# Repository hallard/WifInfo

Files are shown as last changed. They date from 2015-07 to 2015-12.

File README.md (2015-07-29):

WifInfo : Wifi Teleinfo server
==============================

This is a server board for Teleinfo French Meter Measure Library, it can be used as a stand alone device web server that can display/send Teleinfo information.

You can see Teleinformation official french datasheet [there][1]

Since this is really dedicated to French energy measuring system, I will continue in French

Pour le moment le logiciel utilisé doit être considéré comme une version béta (voir alpha), même si le hardware est parfaitement fonctionnel, la partie logicielle est loin d'être terminée.

##Fonctionnalités Terminées
- Mise à jour par Wifi (pas besoin de cable) 
- Affichage dans l'interface Web des données de Teleinfo 
- Affichage dans l'interface Web des données système 
- REST API du type http://wifinfo/papp pour récupérer l'étiquette PAPP (par exemple)

##Fonctionnalités à écrire
A terme les fonctionnalités de cette carte seront les suivantes :
- Créer la page WEB de connexion a un Wifi local 
- Créer la page WEB de configuration du Module 
- Envoi des données de téléinfo vers EMONCMS
- Envoi des données de téléinfo vers les box domotique (JEEDOM, EEDOMUS, ...)
- D'autres idées arriveront surement en cours de route...

Vous trouverez un article dédié à cette carte sur mon [blog][3]

##Schémas  
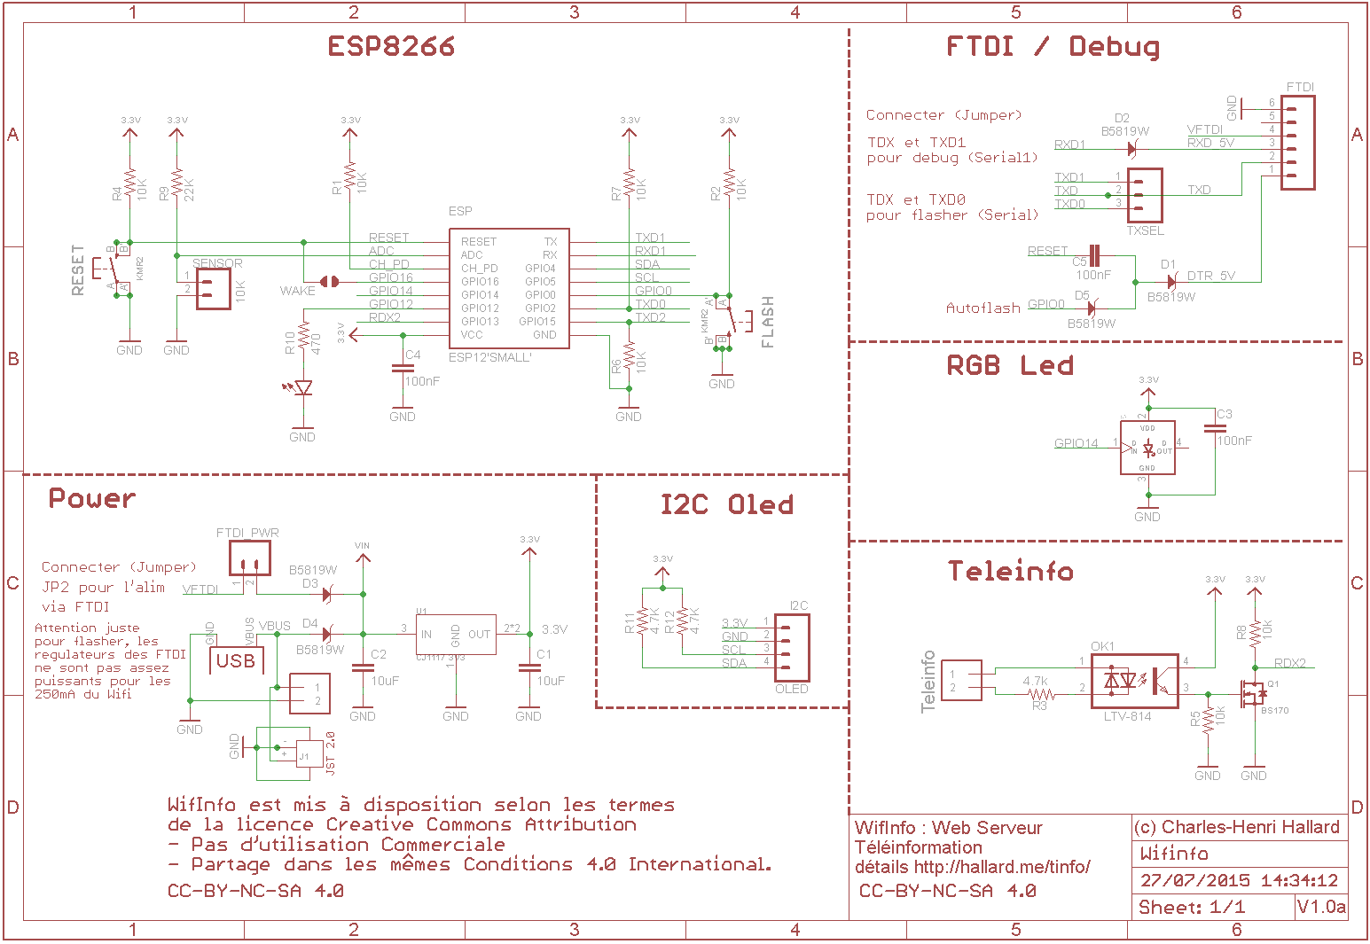
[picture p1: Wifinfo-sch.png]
schematic
  

##Cartes 
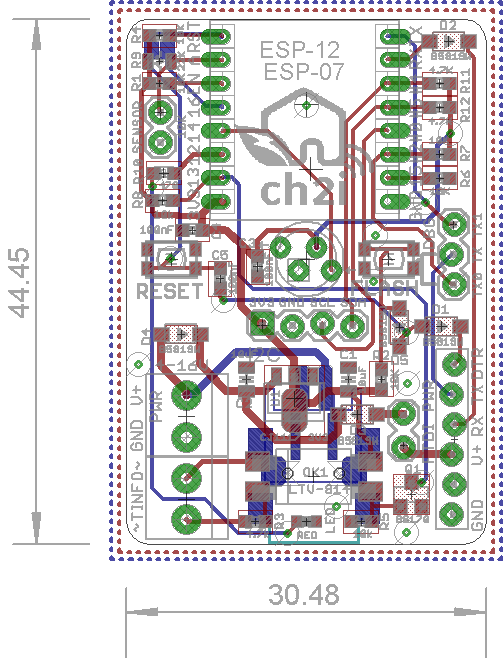
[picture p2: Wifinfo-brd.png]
board V1.0
&nbsp;
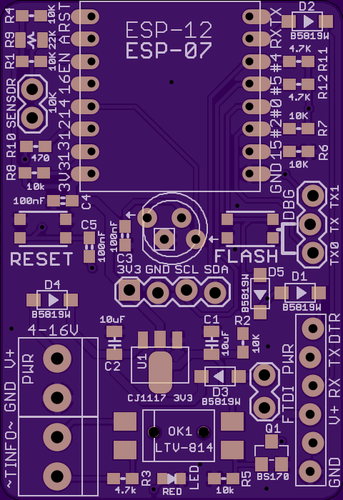
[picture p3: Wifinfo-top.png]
top V1.0
&nbsp;
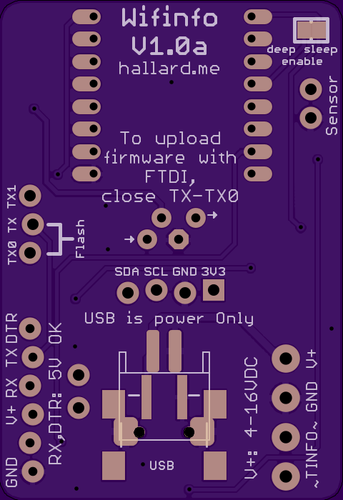
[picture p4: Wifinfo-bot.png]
bottom V1.0


##Documentation de la libraire LibTeleinfo
J'ai écrit un article [dédié][10] sur la librairie téléinfo qui est utilisée dans ce module. Vous pouvez aussi voir les [catégories][6] associées à la téléinfo sur mon [blog][7].

Pour les commentaires et le support vous pouvez allez sur le [forum][8] dédié ou dans la [communauté][9] 

##Sketch d'exemple
- [ESP8266_WebInfo][5] ESP8266 Web dynamic + Rest application. Attention version béta en cours de développement mais parfaitement fonctionnelle. 
- Article dédié à la carte [WifInfo][3]

##License
<br /><span xmlns:dct="http://purl.org/dc/terms/" property="dct:title">Wifinfo</span> by <a xmlns:cc="http://creativecommons.org/ns#" href="https://github.com/hallard/WifInfo" property="cc:attributionName" rel="cc:attributionURL">Charles-Henri Hallard</a> is licensed under a <a rel="license" href="http://creativecommons.org/licenses/by-nc-sa/4.0/">Creative Commons Attribution-NonCommercial-ShareAlike 4.0 International License</a>.<br />Based on a work at <a xmlns:dct="http://purl.org/dc/terms/" href="https://github.com/hallard/WifInfo" rel="dct:source">https://github.com/hallard/WifInfo</a>.

[1]: http://www.erdf.fr/sites/default/files/ERDF-NOI-CPT_02E.pdf
[2]: http://learn.adafruit.com/arduino-tips-tricks-and-techniques/arduino-libraries
[3]: https://hallard.me/wifiinfo/
[5]: https://github.com/hallard/LibTeleinfo/tree/master/examples/ESP8266_WifInfo
[6]: https://hallard.me/category/tinfo/
[7]: https://hallard.me
[8]: https://community.hallard.me/category/7
[9]: https://community.hallard.me
[10]: https://hallard.me/libteleinfo

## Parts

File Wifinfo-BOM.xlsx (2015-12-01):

WifInfo BOM
Composants à positionner
Parts | Qty | Value | Device | Package | Sourcing | Description
R9 | 1 | 100K | RESISTOR0805-RES | 0805-RES |  | Resistor 100K 1%
C3, C4, C5 | 3 | 100nF | CAP0603-CAP | 0603-CAP |  | Capacitor
R1, R2, R4, R5, R6, R7, R8 | 7 | 10K | RESISTOR0603-RES | 0603-RES |  | Resistor
C1, C2 | 2 | 10uF | CAP0805-CAP | 0805-CAP |  | Capacitor
R3, R11, R12 | 3 | 4.7K | RESISTOR0603-RES | 0603-RES |  | Resistor
R10 | 1 | 470 | RESISTOR0603-RES | 0603-RES |  | Resistor
D1, D2, D3, D4, D5 | 5 | B5819W | DIODE-SCHOTTKY | SOD123 |  | Diodes schottky 1A 20V
LED | 1 | RED | LED0603 | 0603-LED
Q1 | 1 | BSS214 | BSS214NH6327XT | SOT23 | mouser (http://www.mouser.fr/ProductDetail/Infineon-Technologies/BSS214NH6327XT) | MOSFET N, BSS214 BSS170 ou CJ2302
U1 | 1 | CJ1117 3V3 | AZ1117CR-3.3TRG1 | SOT89 | mouser (http://www.mouser.fr/Search/ProductDetail.aspx?R=AZ1117CR-3.3TRG1) | 1A Low Dropout 3V3 Linear Regulator
ESP | 1 | ESP8266 | ESP-12F |  | ElectroDragon (http://www.electrodragon.com/product/esp-12f-esp8266-wifi-board/) | ESP8266 Wifi module 12
FLASH, RESET | 2 | KMR2 | PTS810 SJK 250 SMTR LFS | 4.6X2.8 | mouser (http://www.mouser.fr/search/ProductDetail.aspx?R=PTS810-SJK-250-SMTR-LFS) | SMT Tactiles Switches
OK1 | 1 | LTV-814 | LTV-814S | DIL4-SMD | mouser (http://www.mouser.fr/Search/ProductDetail.aspx?R=LTV-814Svirtualkey57820000virtualkey859-LTV-814S) | Optocoupler, Phototransistor Output, AC Input
USB | 1 | USB | USB_POWER | USB_MINIB_POWER |  | Connecteur USB
L1 | 1 | WS2812 | PL9823-F5 | PTH | AliExpress (http://www.aliexpress.com/item/Wholesale-100PCS-PL9823-F5-5mm-round-hat-RGB-LED-P9823-chipset-inside-Full-color-LED-Chip/32378709519.html) | RGB LED with integrated controller 5MM
Connectique
FTDI_PWR | 1 | FTDI PWR | M02LOCK | 1X02-2.54mm |  | Header 2 points Male 2.54mm
TXSEL | 1 |  | M03LOCK | 1X03-2.54mm |  | Header 3 points Male 2.54mm
FTDI | 1 | FTDI con | M06LOCK | 1X06-2.54mm |  | Header 6 points Male 2.54mm
OLED | 1 | I2C con | M04LOCK | 1X04-2.54mm |  | Header 4 points femelle 2.54mm
PWR, TINFO | 2 | 1X2-3.5MM | 1X2-3.5MM | 1X2 points 3.5MM |  | 3.5mm Terminal block 2x2pt ou 1x4pt

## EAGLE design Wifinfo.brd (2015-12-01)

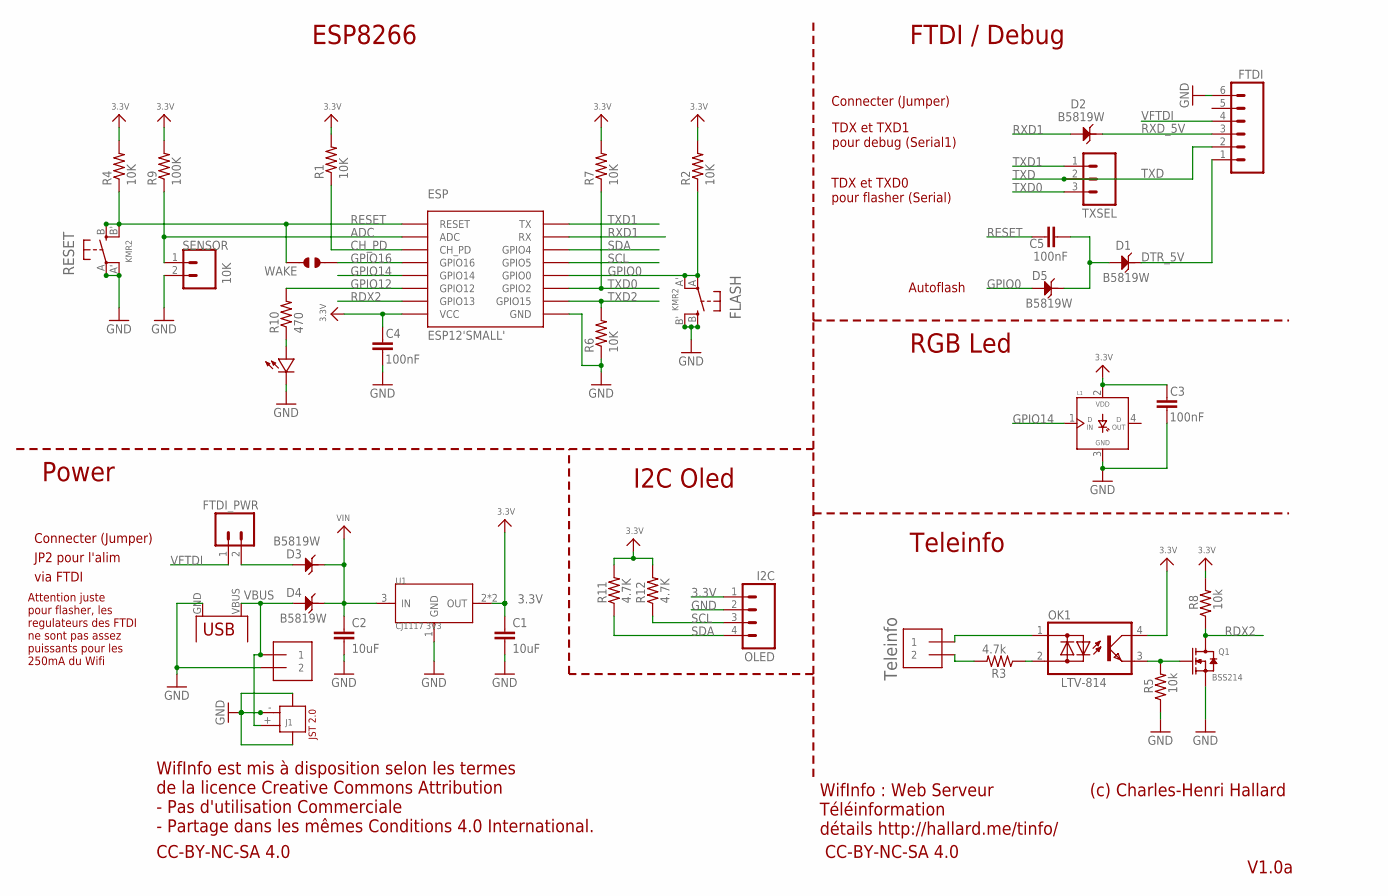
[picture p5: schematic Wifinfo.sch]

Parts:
C1, C2: 10uF; 0805-CAP
C3, C4, C5: 100nF; 0603-CAP
D1, D2, D3, D4, D5: B5819W; SOD123-2.7X1.6
ESP: ESP12'SMALL'; ESP08
FLASH: KMR2; BTN_KMR2_4.6X2.8
FTDI: M06SIP_LOCK_NO_SILK; 1X06-SIP_LOCK_NOSILK
FTDI_PWR: M02LOCK; 1X02_LOCK
J1: JST-2P-SMD'2.0'; 2P-SMD-2.0-90D
L1: WS2812B; WS2812-PTH
LED: RED; 0603-LED
OK1: LTV-814; DIL4-SMD
OLED: I2C; 1X04_LOCK
PWR: 1X2-3.5MM
Q1: BSS214; SOT23
R1, R2, R4, R6, R7: 10K; 0603-RES
R3: 4.7k; 0603-RES
R5, R8: 10k; 0603-RES
R9: 100K; 0805-RES
R10: 470; 0603-RES
R11, R12: 4.7K; 0603-RES
RESET: KMR2; BTN_KMR2_4.6X2.8
SENSOR: 10K; 1X02
TINFO: 1X2-3.5MM
TXSEL: M03LOCK; 1X03_LOCK
U1: CJ1117 3V3; SOT89
USB: USB; USB_MINIB_POWER
WAKE: JUMPER_SOLDER_1X2

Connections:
3.3V: C1.1, C3.2, C4.2, ESP.VCC, L1.2 (VDD), OK1.4 (C), OLED.1, R1.2, R2.2, R4.2, R7.2, R8.2, R9.2, R11.2, R12.2, U1.2 (OUT), U1.4 (OUT)
ADC: ESP.ADC, R9.1, SENSOR.1
CH_PD: ESP.CH_PD, R1.1
DTR_5V: D1.2, FTDI.1
GND: C1.2, C2.2, C3.1, C4.1, ESP.GND, FLASH.B (S), FLASH.B' (S1), FTDI.6, J1.3, J1.4, J1.- (2), L1.3 (GND), LED.MINUS, OLED.2, PWR.2, Q1.2 (S), R5.1, R6.1, RESET.A, RESET.A' (P1), SENSOR.2, U1.1 (GND), USB.GND
GPIO0: D5.1, ESP.GPIO0, FLASH.A, FLASH.A' (P1), R2.1
GPIO12: ESP.GPIO12, R10.2
GPIO14: ESP.GPIO14, L1.1 (DIN)
GPIO16: ESP.GPIO16, WAKE.2
unnamed: OK1.3 (E), Q1.1 (G), R5.2
unnamed: D3.1, FTDI_PWR.2
unnamed: OK1.2 (AC2), R3.1
unnamed: OK1.1 (AC1), TINFO.1
unnamed: R3.2, TINFO.2
unnamed: LED.PLUS, R10.1
unnamed: C5.1, D1.1, D5.2
RDX2: ESP.GPIO13, Q1.3 (D), R8.1
RESET: C5.2, ESP.RESET, R4.1, RESET.B (S), RESET.B' (S1), WAKE.1
RXD1: D2.1, ESP.RX
RXD_5V: D2.2, FTDI.3
SCL: ESP.GPIO5, OLED.3, R12.1
SDA: ESP.GPIO4, OLED.4, R11.1
TXD: FTDI.2, TXSEL.2
TXD0: ESP.GPIO2, R7.1, TXSEL.3
TXD1: ESP.TX, TXSEL.1
TXD2: ESP.GPIO15, R6.2
VBUS: D4.1, J1.+ (1), PWR.1, USB.VBUS (VCC)
VFTDI: FTDI.4, FTDI_PWR.1
VIN: C2.1, D3.2, D4.2, U1.3 (IN)

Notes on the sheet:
Teleinfo
WifInfo : Web Serveur Téléinformation détails http://hallard.me/tinfo/
CC-BY-NC-SA 4.0
WifInfo est mis à disposition selon les termes de la licence Creative Commons Attribution - Pas d'utilisation Commerciale - Partage dans les mêmes Conditions 4.0 International.
(c) Charles-Henri Hallard
Power
ESP8266
FTDI / Debug
RGB Led
I2C Oled
TDX et TXD0 pour flasher (Serial)
TDX et TXD1 pour debug (Serial1)
Connecter (Jumper)
JP2 pour l'alim
via FTDI
Attention juste pour flasher, les regulateurs des FTDI ne sont pas assez puissants pour les 250mA du Wifi
JST 2.0
Autoflash
V1.0a

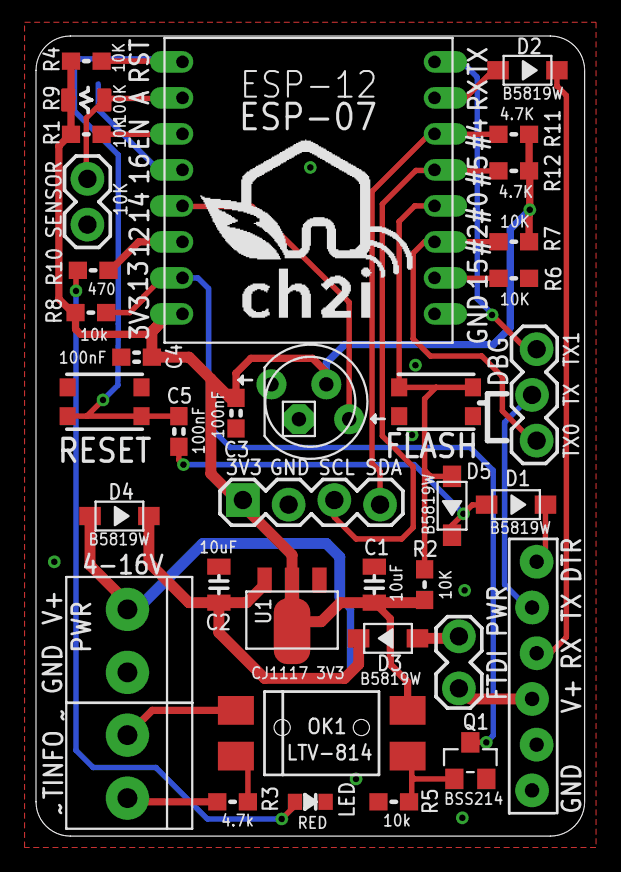
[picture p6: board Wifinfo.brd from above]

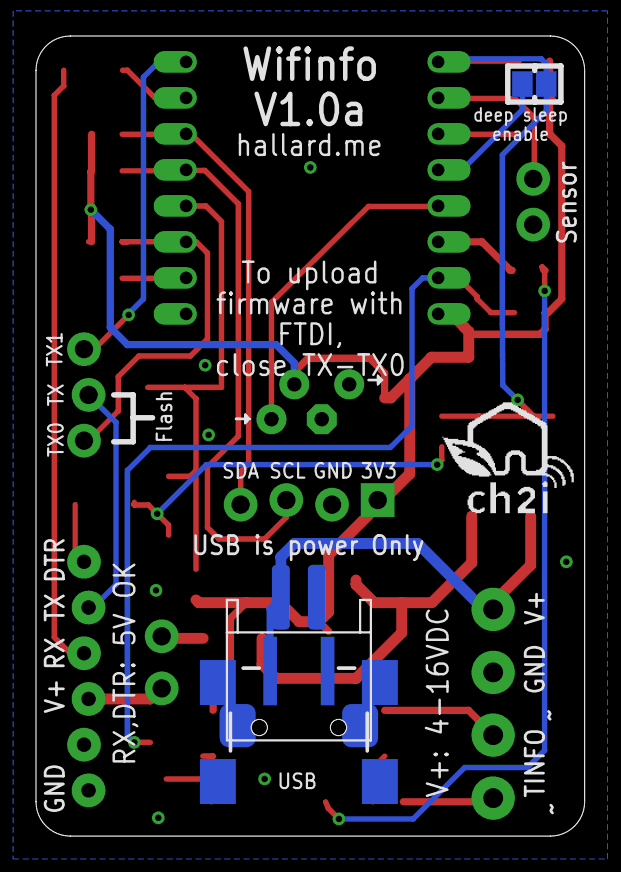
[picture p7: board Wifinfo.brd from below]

Board: 2 copper layers, 30.5 x 44.5 mm, 42 parts (4 on the bottom side), 29 nets.

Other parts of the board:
U$11: LOGO_CH2I_110MM
U$12: LOGO_CH2I_75MM

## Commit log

2015-07-27 Ajout fonction auto-flash
    Ajout fonction auto flash, pour pouvoir flasher le module avec un
    adaptateur FTDI like mais sans devoir appuyer sur le bouton flash
    [Wifinfo.brd, Wifinfo.sch]
2015-12-01 Minor Adjustments
    Minor Adjustments
    [Wifinfo-BOM.xlsx, Wifinfo.brd, Wifinfo.sch]

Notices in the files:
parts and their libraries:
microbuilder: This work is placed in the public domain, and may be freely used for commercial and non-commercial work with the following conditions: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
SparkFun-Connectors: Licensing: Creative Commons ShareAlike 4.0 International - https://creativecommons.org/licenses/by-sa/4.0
